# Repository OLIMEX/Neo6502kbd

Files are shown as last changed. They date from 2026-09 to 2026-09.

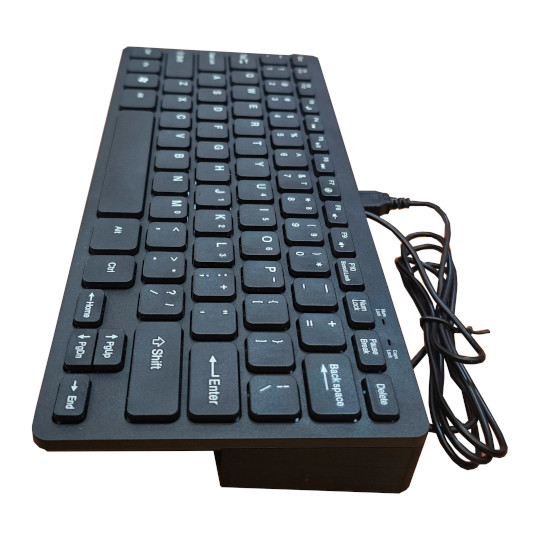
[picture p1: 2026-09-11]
DOCUMENTS/Neo6502kbd-2.jpg

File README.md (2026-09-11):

# Neo6502kbd
Neo6502kbd is all in one Retro computer with 6502 processor, Keyboard, Four USB hosts and DVI/HDMI output.

With Reload emulator you can run Apple ][ and Oric Atmos emulators.

[Neo6502kbd-1](DOCUMENTS/Neo6502kbd-1.jpg)

https://www.olimex.com/Products/Retro-Computers/Neo6502kbd/open-source-hardware

## Licensee
* Hardware is released under CERN Open Hardware Licence Version 2 - Strongly Reciprocal
* Software is released under MIT Licensee
* Documentation is released under CC BY-SA 4.!

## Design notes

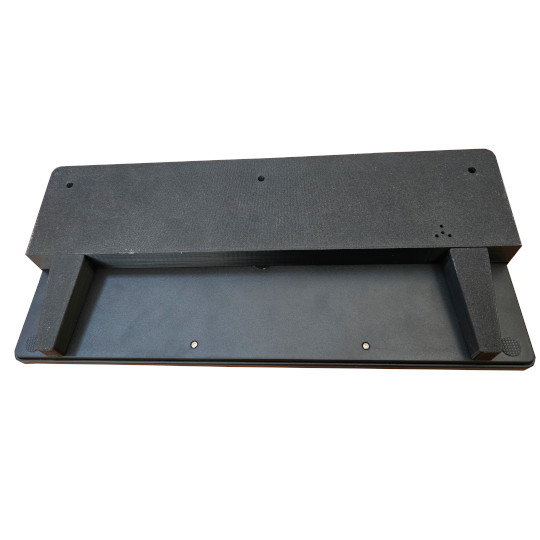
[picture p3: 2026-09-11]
DOCUMENTS/Neo6502kbd-5.jpg

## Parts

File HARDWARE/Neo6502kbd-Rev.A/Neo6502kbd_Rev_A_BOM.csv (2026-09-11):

Quantity | Value | Footprint | Reference
2 | LED/RED/0603 | LED_0603_KA | Act/Sus1, PWR_LED1
1 | SIDE_B3F-3150 | B3F-31XX | BOOT1
1 | PLASTIC CAP BLACK FOR B3F-3150(B32-2010(black)) | BUT-CAP_B32-2010(black) | BOOT1-1
21 | 100nF/10V/20%/X5R/C0402 | C_0402_5MIL_DWS | C1, C2, C3, C4, C5, C6, C7, C8, C9, C10, C13, C14, C22, C24, C32, C37, C38, C39, C41, C42, C44
5 | 2.2uF/6.3V/20%/X5R/C0402 | C_0402_5MIL_DWS | C11, C12, C40, C43, C45
2 | 27pF/50V/5%/C0G/C0402 | C_0402_5MIL_DWS | C15, C16
4 | 22uF/6.3V/20%/X5R/C0603 | C_0603_5MIL_DWS | C18, C28, C35, C36
3 | 10uF/6.3V/20%/X5R/C0402 | C_0402_5MIL_DWS | C20, C21, C23
3 | 47uF/6.3V/20%/X5R/C0805 | C_0805_5MIL_DWS | C27, C33, C34
2 | 1N5822/SS34/SMA | SMA-KA | D1, D3
1 | 1N4148W/SOD123 | SOD-123_1C-2A_KA | D2
1 | HDMI-SWM-19 | HDMI-SWM-19_Paste | DVI1
1 | 1.0uH/4.2A/DCR=35mR/20%/2.00x1.60x1.00mm/L2016(PIM201610-1R0MTS00) | L_2016_MM | L1
4 | LED/GREEN/0603 | LED_0603_KA | LED_HOST1, LED_HOST2, LED_HOST3, LED_HOST4
1 | SS-12D11G5 | SS-12D11G5 | PWR_OFF/ON1
2 | Q12MHz/18pF/30ppm/4P/3.2x2.5mm(ABM8-12.000MHZ-D2Y-T) | TSX-3.2x2.5mm_GND(3) | Q1, Q2
1 | BC817-40(SOT23) | SOT23 | Q3
7 | 2.2k/R0402 | R_0402_5MIL_DWS | R1, R20, R21, R22, R27, R46, R50
15 | 10k/R0402 | R_0402_5MIL_DWS | R2, R13, R14, R16, R17, R19, R24, R28, R29, R30, R31, R32, R41, R42, R43
1 | 1k/R0402 | R_0402_5MIL_DWS | R4
2 | 27R/R0402 | R_0402_5MIL_DWS | R5, R6
4 | 5.1k/1%/R0402 | R_0402_5MIL_DWS | R7, R9, R44, R45
1 | 100R/R0402 | R_0402_5MIL_DWS | R8
1 | 56.2k/1%/R0402 | R_0402_5MIL_DWS | R10
1 | 12.4k/1%/R0402 | R_0402_5MIL_DWS | R11
1 | 33k/R0402 | R_0402_5MIL_DWS | R12
1 | 2.7k/1%/R0402 | R_0402_5MIL_DWS | R15
1 | 4.7k/R0402 | R_0402_5MIL_DWS | R18
1 | 150R/R0402 | R_0402_5MIL_DWS | R23
9 | 270R/R0402 | R_0402_5MIL_DWS | R25, R33, R34, R35, R36, R37, R38, R39, R40
1 | 47R/R1206 | R_1206_5MIL_DWS | R26
3 | 0R/R0402 | R_0402_5MIL_DWS | R47, R48, R49
2 | RA1206_(4x0603)_4B8_330R | RA1206_(4X0603)_4B8_xx | RM1, RM2
1 | Speaker_QMB-09B-03(1.5-5.0V_2.7kHz_F9.0mm*H5.5mm) | Speaker_QMB-09B-03_1-Plus_2-Minus | SPK1
1 | LMUN2235LT1G(SOT-23) | SOT23 | T1
1 | P25Q16SH-SUH-IR(SOIC-8_208mils) | SO-8_208mil | U1
1 | TPS62A02ADRLR(SOT-563-6) | SOT-563-6 | U2
1 | RP2040(QFN-56_7x7mm_P0.4mm) | QFN56_7x7_Pitch_0.4mm | U3
1 | CH217K(SOT23-6L) | SOT23-6 | U4
1 | FE1.1s(SSOP-28) | SSOP28_10x4mm_Pitch_0.64mm | U5
1 | W65C02S6TQTG-14(TQFP44) | TQFP44_NEO6502 | U6
3 | 74LVC245APW(TSSOP20) | TSSOP20_Pitch-0.65mm_6.6x4.5x1.2mm | U7, U8, U9
1 | BH10R | BH10R | UEXT1
4 | USB-A-SMT-6.3H | USB-A-SMT-6.3H_HOST_Female | USB-HOST1, USB-HOST2, USB-HOST3, USB-HOST4
2 | USB-C-16P-F(A40-00119-A52-12) | USB2.0_TYPE-C(A40-00119-A52-12)_Paste | USB-PGM1, USB-PWR1

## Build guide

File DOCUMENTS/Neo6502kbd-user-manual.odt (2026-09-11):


Neo6502kbd

User Manual

Rev.1.0 August 2026 olimex.com

# Introduction to Neo6502

The design goal with Neo6502 was to make simple modern retro computer with 6502 processor.

By modern we mean computer with modern video interface like HDMI, USB keyboard and USB Flash drive as storage. HDMI as everyone have TV with HDMI at home and USB keyboards now are mainstream device for input.

With the task to provide HDMI and USB interface we choose RP2040 which already have DVI bit bang project and USB host.

RP2040 also have enough RAM so we decided to use RP2040 to emulate also the RAM memory for 6502.

For the 6502 processor we choose W65C02 from WDC as they are still in mass production and can be purchased freely.

The Neo name was taken for two reasons, first it imply the modern design, then we liked the analogy with the movie The Matrix as W65C02 lives in virtual world and thinks it have real memory, video and keyboard but actually all this is virtual and emulated by RP2040.

Neo6502 is Open Source Hardware, all CAD files and firmware and available, so people can study and modify.

Neo6502kbd is new derivate of Neo6502 it includes other peripherials which were not available on the original Neo6502 – embedded keyboard and USB hub.

All software and code for Neo6502 will run same way on Neo6502kbd.

The features of Neo6502kbd are:

- real W65C02 processor executing every instruction as it was executed in early retro computers, no emulation for the processor, all timing is exact
- RP2040 with 2MB of SPI Flash, east to load new firmware via drag and drop virtual drive
- HDMI output
- USB host which can be used for programming and to connection to keyboard, mouse, USB Flash etc
- Audio buzzer which you can enable/disable
- USB-C connector for power supply and programming
- UEXT connector with I2C, UART and SPI for connecting to external boards
- On Off slide switch
- RP2040 programming bootloader button
- Dimension 285 x 123 x30mm

## Order codes for Neo6502kbd and accessories:

Neo6502kbd (https://www.olimex.com/Products/Retro-Computers/Neo6502kbd/open-source-hardware) All in one modern retro computer with 6502 processor

CABLE-USB-A-C-1M (https://www.olimex.com/Products/Components/Cables/CABLE-USB-A-C-1M/) USB-C cable for power supply

CABLE-HDMI-50CM (https://www.olimex.com/Products/Components/Cables/CABLE-HDMI-50CM/) HDMI cable

UEXT modules (https://www.olimex.com/Products/Modules/) many UEXT modules which can connect to Neo6502 UEXT connector

# HARDWARE

## Neo6502kbd layout:

Back view:


Power USB-C

DVI/HDMI

Four USB-C hosts

## Neo6502kbd schematics:

Neo6502kbd latest schematic is on GitHub (https://github.com/OLIMEX/Neo6502kbd/blob/main/HARDWARE/Neo6502kbd-Rev.A/Neo6502kbd_Rev_A.pdf)

## UEXT connector:

UEXT connector stands for Universal EXTension connector and contain +3.3V, GND, I2C, SPI, UART signals.

UEXT connector can be in different shapes.

The original UEXT connector is 0.1” 2.54mm step boxed plastic connector. All signals are with 3.3V levels.

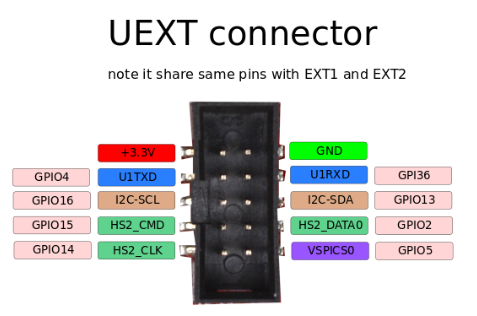
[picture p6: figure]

Olimex has developed number of MODULES (https://www.olimex.com/Products/Modules/) with this connector. There are temperature, humidity, pressure, magnetic field, light sensors. Modules with LCDs, LED matrix, Relays, Bluetooth, Zigbee, WiFi, GSM, GPS, RFID, RTC, EKG, sensors and etc.

Neo6502kbd UEXT connector is wired to RP2040 GPIOs as follows:

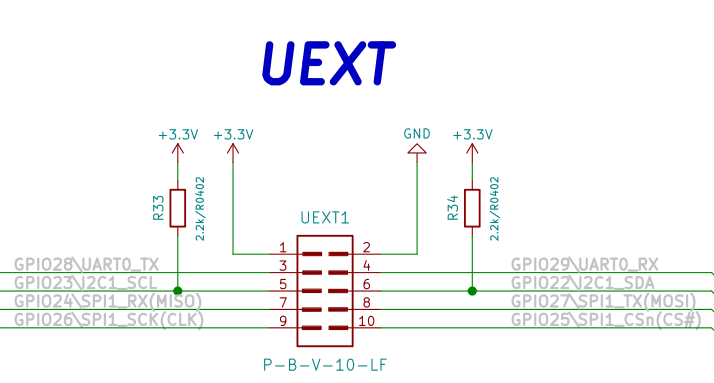
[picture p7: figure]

# SOFTWARE:

Neo6502 is open flexible system as everything is virtual and depend on RP2040 firmware, this allow you to emulate old architectures like Apple ][ and Oric Atmos, or to make your own completely new architecture.

Veselin Sladkov (veselin.sladkov@gmail.com) did amazing work for Neo6502 and created Apple ][, Oric Atmos and Apple Iic emulation with Reload emulator (https://github.com/vsladkov/reload-emulator).

The reload emulator require some ROMs and disks which are hosted on olimex’s ftp (https://ftp.olimex.com/Neo6502/).

Rien Matthijsse (rien@marobi.com) made several versions of RP2040 memulator and EHBasic port working on Neo6502 in his GitHub repository (https://github.com/marobi).

Paul Robson (paul@robsons.org.uk ) made special version of Neo6502 Basic on GitHub (https://github.com/paulscottrobson/neo6502) and web browser emulator (http://www.robsons.org.uk/neo6502/neo.html).

## Programming RP2040

The RP2040 firmware is UF2 file. You can get pre-build firmware of reload emulator on olimex’s ftp.

We recommend you for Apple ][ to use: https://ftp.olimex.com/Neo6502/uf2/apple2_800x600_400MHz.uf2

This firmware have latest PRODOS and several games on it ready to play.

For Oric Atmos we recommend you to use:

https://ftp.olimex.com/Neo6502/uf2/oric_960x540_372MHz.uf2

To play Total Replay you need this uf2 file:

https://ftp.olimex.com/Neo6502/apple2e-5.uf2

And you need USB Flash drive with Total Replay 5.1

https://ftp.olimex.com/Neo6502/Total%20Replay%20v5.1.hdv

To program the .uf2 files you need USB A to C cable.

Plug the cable to the left side USB-C connector (PGM)

Press the bootloader button and switch the power on. Your computer will show new drive. Once this new drive show copy the .uf2 file to it. Once the firmware is programmed the drive will dissapear. This means the RP2040 now have the new firmware loaded.

You need to disconnect the cable and to attach it to the back side USB-C power supply connector.

# Revision History

Revision 1.0 August 2026

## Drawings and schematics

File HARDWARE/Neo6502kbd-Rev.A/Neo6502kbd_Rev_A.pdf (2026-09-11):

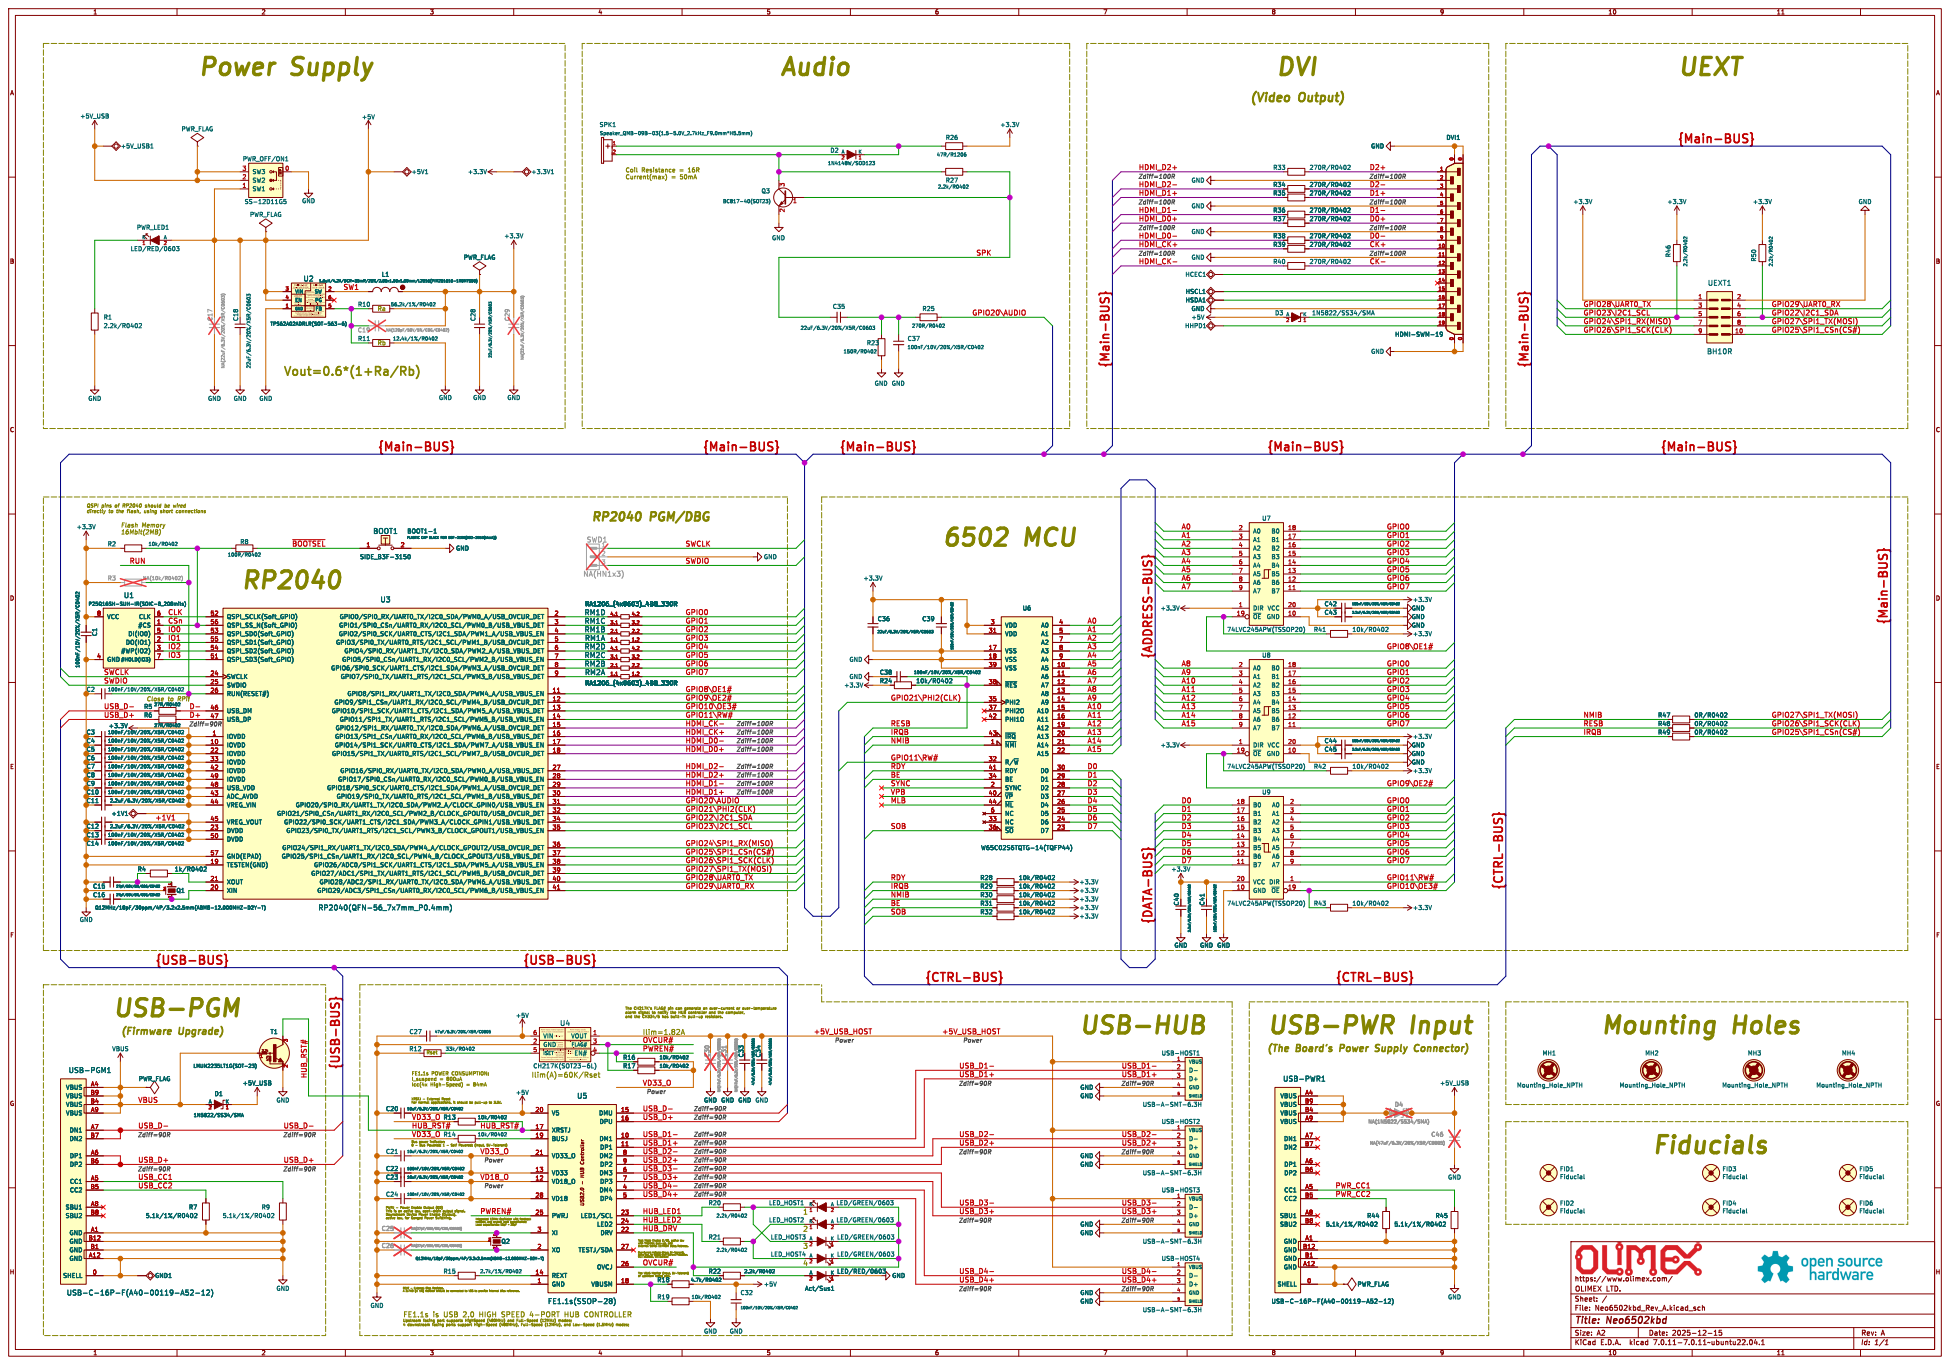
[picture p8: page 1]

In casea loweroutputrippleisdesired,higheroutputcapacitancecanhelpreducetheripple. Lx=1.0uH
Cout=(10~22)uF/6.3V/X5Rþÿ(Vout"e1.8V). 22uFRecommended! Cout=22uF/6.3V/X5Rþÿ(1.2V"dVout<1.8V) Cout=44uF/6.3V/X5Rþÿ(0.6V"dVout<1.2V) DCR<50mR

Donotfloat. Enablecontrol. FB Input Current,I(FB)=100nA(max) FeedbackReferenceVoltage,V(REF)=0.6V
Rb mustnotbehigherthanþÿ100k© toprovideacceptablenoisesensitivity. ShutdownCurrentI(SHDN)=0.01-2uA
SwitchingFrequency 2.4MHz TPS62A02ADRLR V(ENH)=1.2V

Rb Vout=0.6*(1+Ra/Rb)

QSPI pins of RP2040 should be wired
directly to the flash, using short connections Flash Memory

PLASTIC CAP BLACK FOR B3F-3150(B32-2010(black))

connectedto USBportVBUS Currentlimiting thresholdsetting, externalresistorRsetto GND to setIset ground

alarmopen-drainoutput,activelow Common
terminal VIH=(1.8-5.0)V

(The Board's Power Supply Connector)

5 USB-HOST3 USB-A-SMT-6.3H GND

File: Neo6502kbd_Rev_A.kicad_sch Sheet: / OLIMEX LTD. https://www.olimex.com/

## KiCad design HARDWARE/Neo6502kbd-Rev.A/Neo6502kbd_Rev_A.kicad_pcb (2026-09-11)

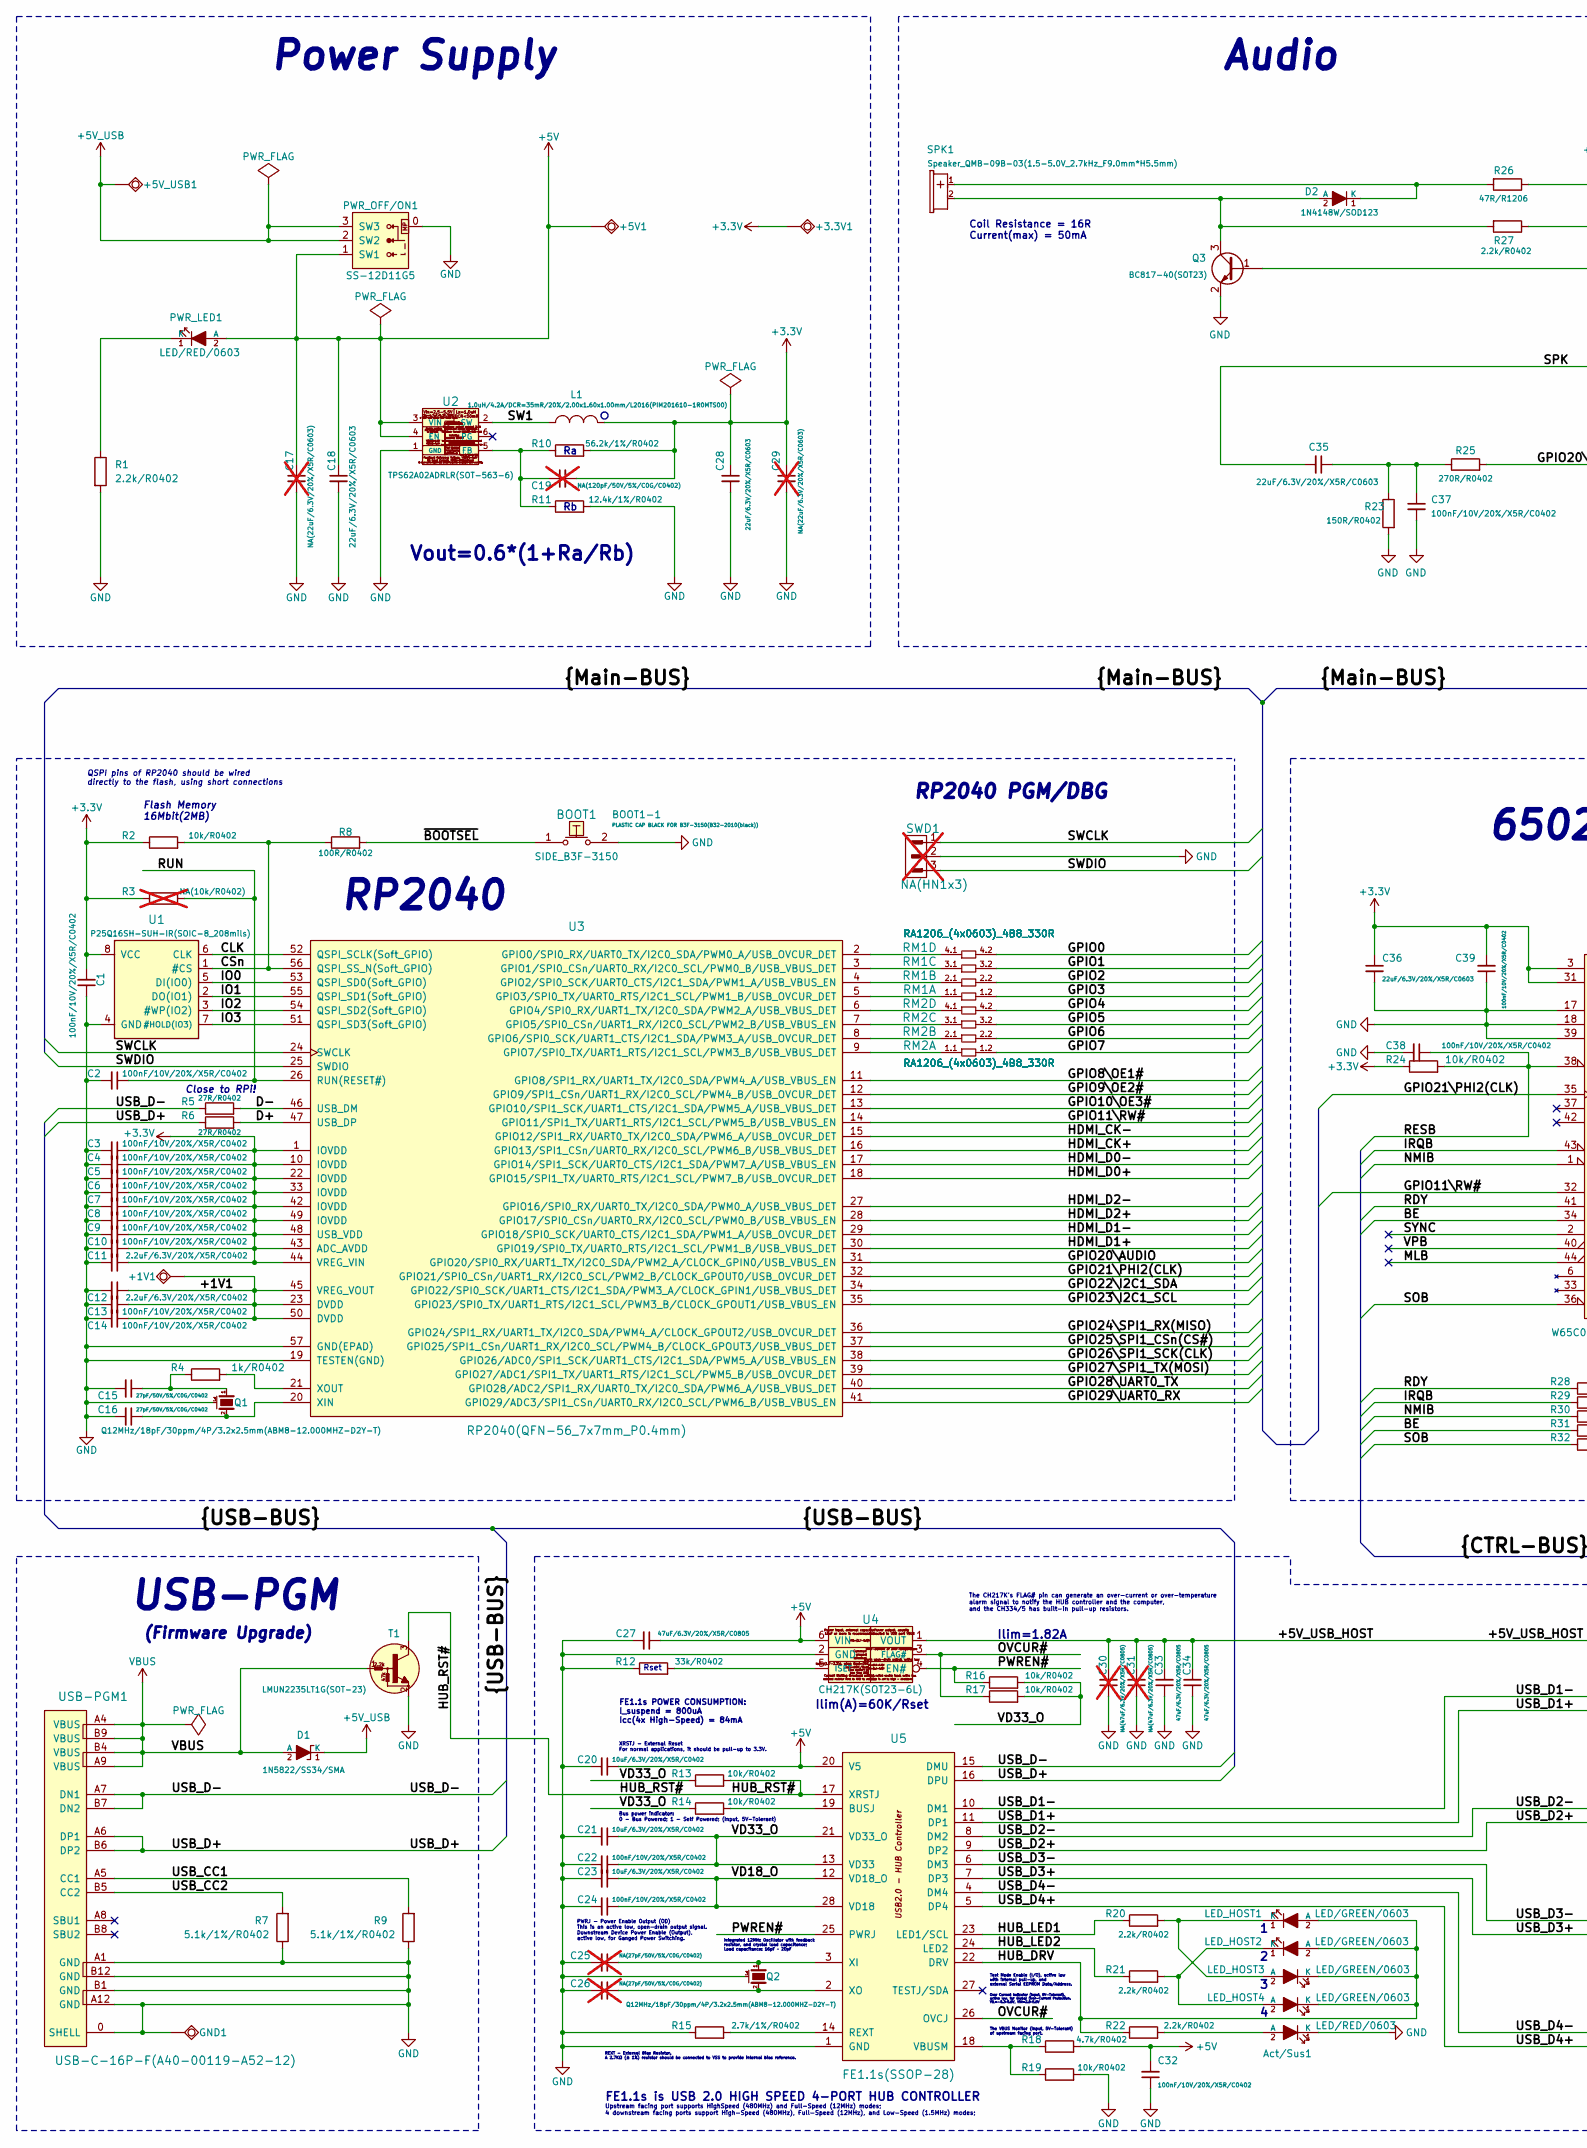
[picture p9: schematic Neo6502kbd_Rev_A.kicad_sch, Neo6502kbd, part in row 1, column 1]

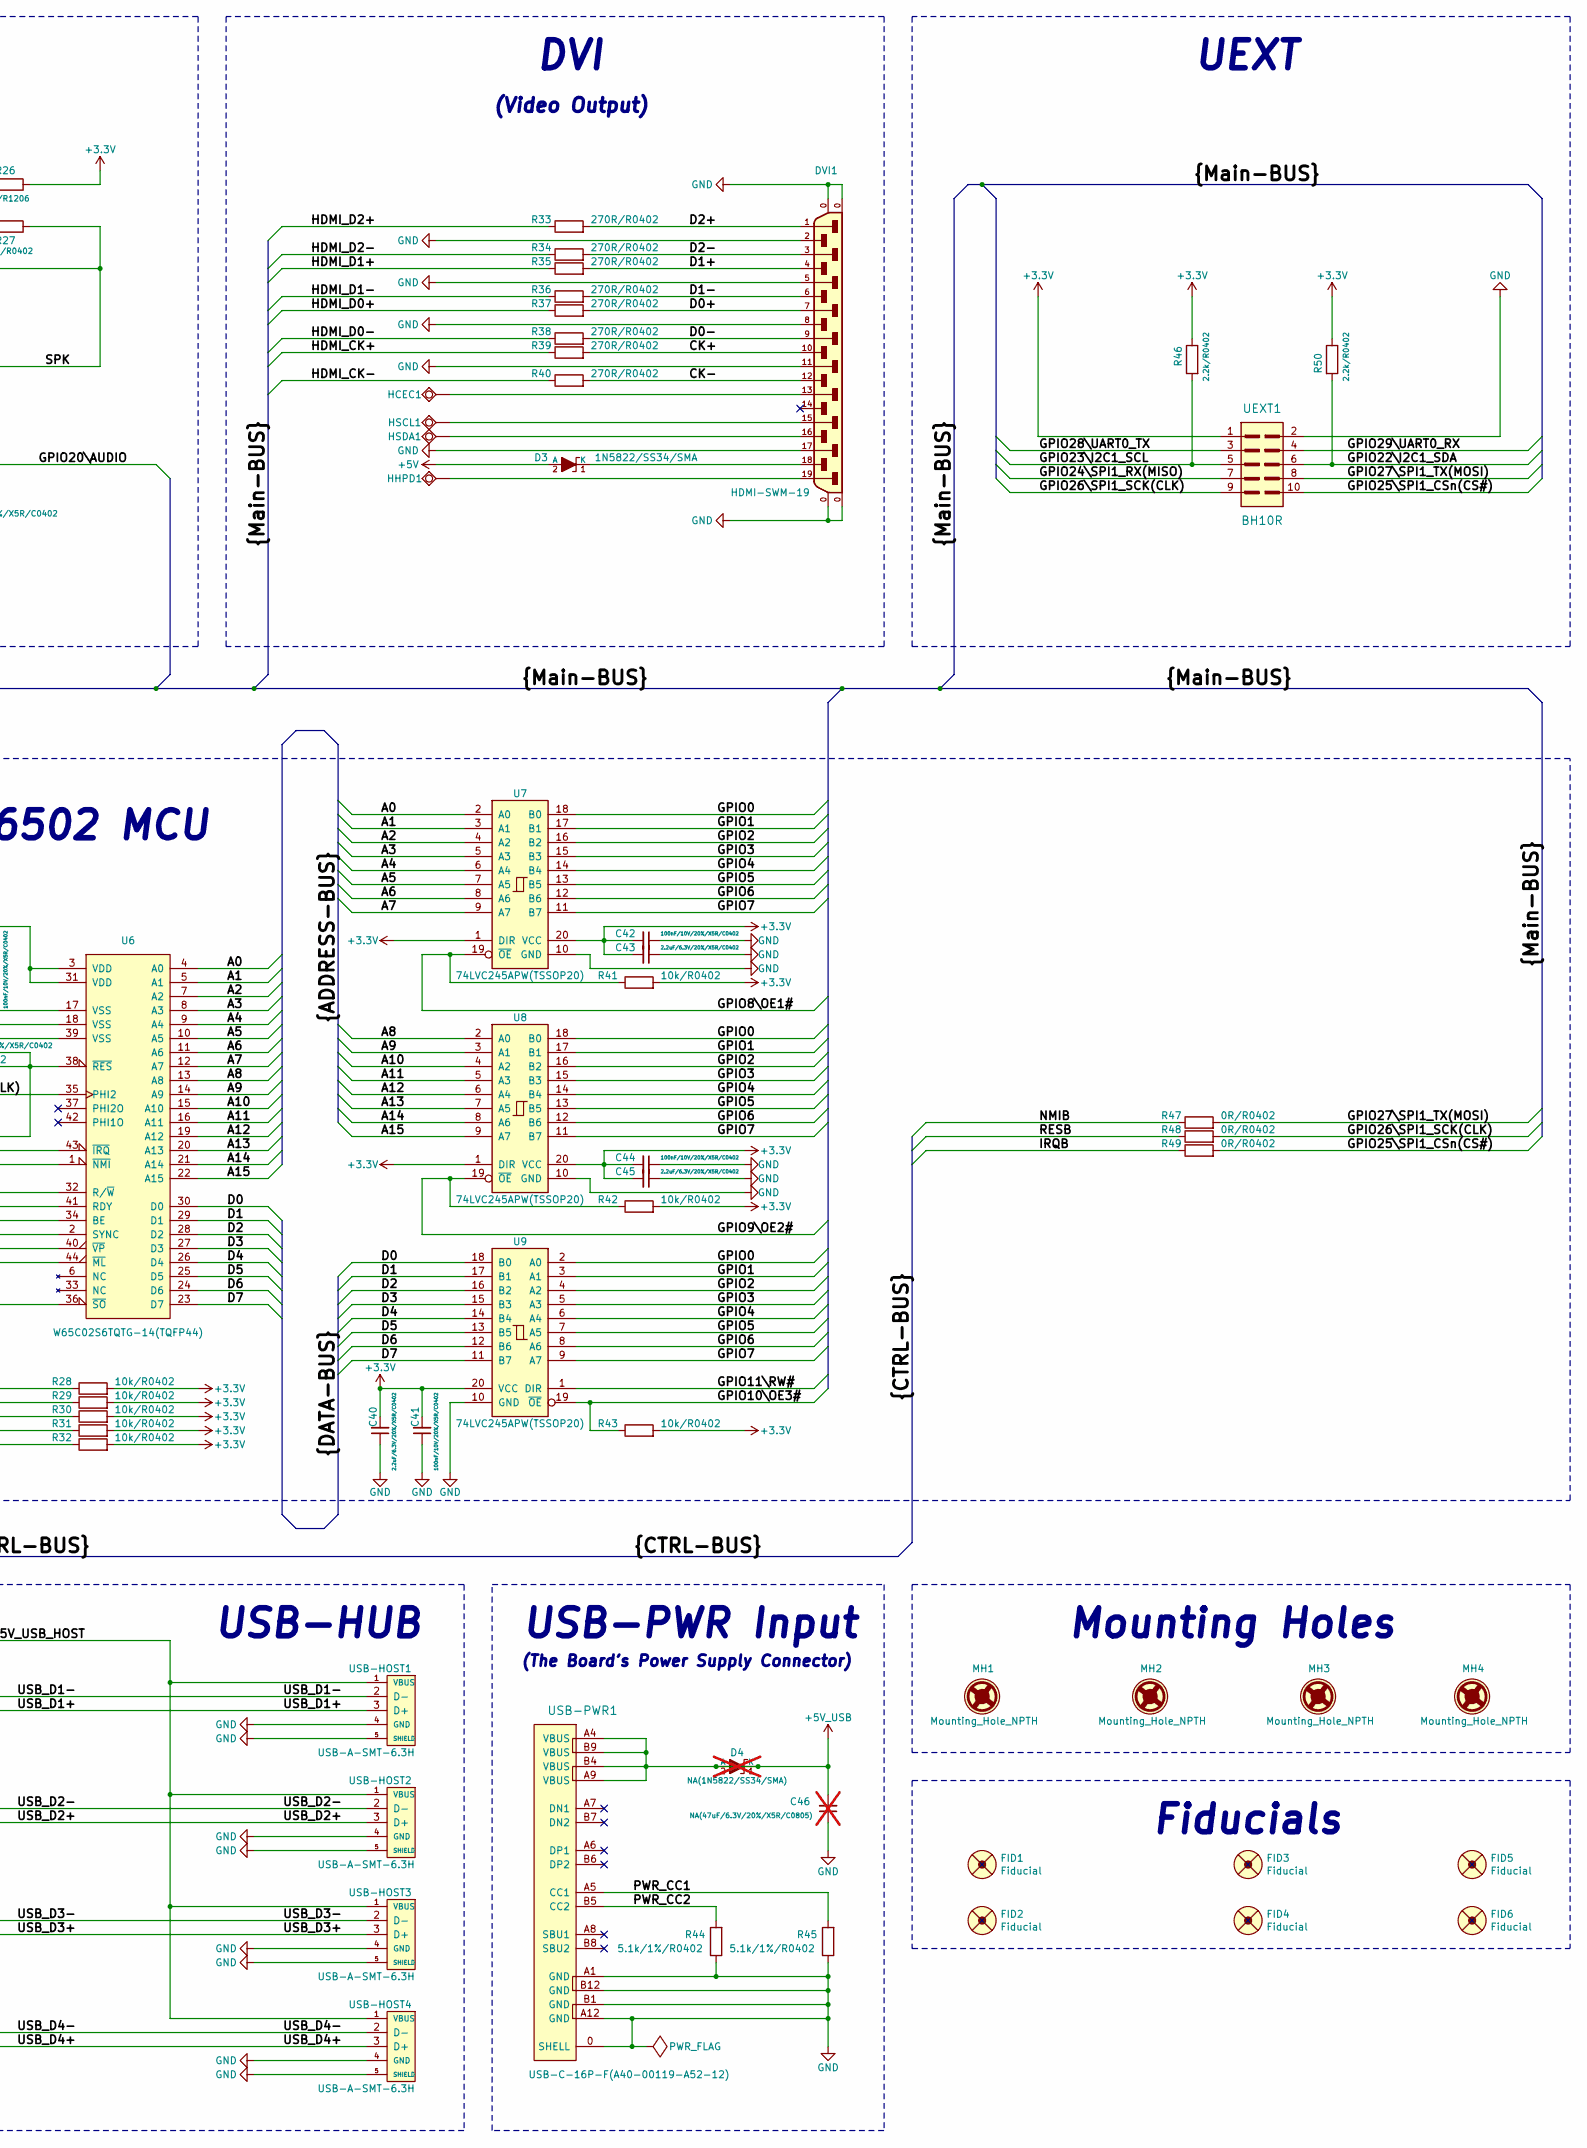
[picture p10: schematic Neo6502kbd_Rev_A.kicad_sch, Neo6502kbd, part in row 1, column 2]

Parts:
+1V1, +3.3V1, +5V1, +5V_USB1: TESTPAD; TEST_PAD40x70_SQUARE
Act/Sus1: LED/RED/0603; LED_0603_KA
BOOT1: SIDE_B3F-3150; B3F-31XX
BOOT1-1: PLASTIC CAP BLACK FOR B3F-3150(B32-2010(black)); BUT-CAP_B32-2010(black)
C1, C2, C3, C4, C5, C6, C7, C8, C9, C10, C13, C14, C22, C24, C32, C37, C38, C39, C41, C42, C44: 100nF/10V/20%/X5R/C0402; C_0402_5MIL_DWS
C11, C12, C40, C43, C45: 2.2uF/6.3V/20%/X5R/C0402; C_0402_5MIL_DWS
C15, C16: 27pF/50V/5%/C0G/C0402; C_0402_5MIL_DWS
C17, C29: NA(22uF/6.3V/20%/X5R/C0603); C_0603_5MIL_DWS; not fitted
C18, C28, C35, C36: 22uF/6.3V/20%/X5R/C0603; C_0603_5MIL_DWS
C19: NA(120pF/50V/5%/C0G/C0402); C_0402_5MIL_DWS; not fitted
C20, C21, C23: 10uF/6.3V/20%/X5R/C0402; C_0402_5MIL_DWS
C25, C26: NA(27pF/50V/5%/C0G/C0402); C_0402_5MIL_DWS; not fitted
C27, C33, C34: 47uF/6.3V/20%/X5R/C0805; C_0805_5MIL_DWS
C30, C31, C46: NA(47uF/6.3V/20%/X5R/C0805); C_0805_5MIL_DWS; not fitted
D1, D3: 1N5822/SS34/SMA; SMA-KA
D2: 1N4148W/SOD123; SOD-123_1C-2A_KA
D4: NA(1N5822/SS34/SMA); SMA-KA; not fitted
DVI1: HDMI-SWM-19; HDMI-SWM-19_Paste
FID1, FID2, FID3: Fiducial; Fiducial1x3_Paste
FID4, FID5, FID6: Fiducial; Fiducial1x3
GND1: TESTPAD; TEST_PAD40x70_SQUARE
HCEC1: TESTPAD; TESTPAD_40-ROUND
HHPD1: TESTPAD; TESTPAD_40-ROUND
HSCL1: TESTPAD; TESTPAD_40-ROUND
HSDA1: TESTPAD; TESTPAD_40-ROUND
L1: 1.0uH/4.2A/DCR=35mR/20%/2.00x1.60x1.00mm/L2016(PI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; L_2016_MM
LED_HOST1, LED_HOST2, LED_HOST3, LED_HOST4: LED/GREEN/0603; LED_0603_KA
MH1, MH2, MH3, MH4: Mounting_Hole_NPTH; Mounting_Hole_Drill-3.3mm_Clerance-7mm
PWR_LED1: LED/RED/0603; LED_0603_KA
PWR_OFF/ON1: SS-12D11G5
Q1, Q2: Q12MHz/18pF/30ppm/4P/3.2x2.5mm(ABM8-12.000MHZ-D2Y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; TSX-3.2x2.5mm_GND(3)
Q3: BC817-40(SOT23); SOT23
R1, R20, R21, R22, R27, R46, R50: 2.2k/R0402; R_0402_5MIL_DWS
R2, R13, R14, R16, R17, R19, R24, R28, R29, R30, R31, R32, R41, R42, R43: 10k/R0402; R_0402_5MIL_DWS
R3: NA(10k/R0402); R_0402_5MIL_DWS; not fitted
R4: 1k/R0402; R_0402_5MIL_DWS
R5, R6: 27R/R0402; R_0402_5MIL_DWS
R7, R9, R44, R45: 5.1k/1%/R0402; R_0402_5MIL_DWS
R8: 100R/R0402; R_0402_5MIL_DWS
R10: 56.2k/1%/R0402; R_0402_5MIL_DWS
R11: 12.4k/1%/R0402; R_0402_5MIL_DWS
R12: 33k/R0402; R_0402_5MIL_DWS
R15: 2.7k/1%/R0402; R_0402_5MIL_DWS
R18: 4.7k/R0402; R_0402_5MIL_DWS
R23: 150R/R0402; R_0402_5MIL_DWS
R25, R33, R34, R35, R36, R37, R38, R39, R40: 270R/R0402; R_0402_5MIL_DWS
R26: 47R/R1206; R_1206_5MIL_DWS
R47, R48, R49: 0R/R0402; R_0402_5MIL_DWS
RM1, RM2: RA1206_(4x0603)_4B8_330R; RA1206_(4X0603)_4B8_xx
SPK1: Speaker_QMB-09B-03(1.5-5.0V_2.7kHz_F9.0mm*H5.5mm); Speaker_QMB-09B-03_1-Plus_2-Minus
SWD1: NA(HN1x3); HN1x3; not fitted
T1: LMUN2235LT1G(SOT-23); SOT23
U1: P25Q16SH-SUH-IR(SOIC-8_208mils); SO-8_208mil
U2: TPS62A02ADRLR(SOT-563-6); SOT-563-6
U3: RP2040(QFN-56_7x7mm_P0.4mm); QFN56_7x7_Pitch_0.4mm
U4: CH217K(SOT23-6L); SOT23-6
U5: FE1.1s(SSOP-28); SSOP28_10x4mm_Pitch_0.64mm
U6: W65C02S6TQTG-14(TQFP44); TQFP44_NEO6502
U7, U8, U9: 74LVC245APW(TSSOP20); TSSOP20_Pitch-0.65mm_6.6x4.5x1.2mm
UEXT1: BH10R
USB-HOST1, USB-HOST2, USB-HOST3, USB-HOST4: USB-A-SMT-6.3H; USB-A-SMT-6.3H_HOST_Female
USB-PGM1: USB-C-16P-F(A40-00119-A52-12); USB2.0_TYPE-C(A40-00119-A52-12)_Paste
USB-PWR1: USB-C-16P-F(A40-00119-A52-12); USB2.0_TYPE-C(A40-00119-A52-12)_Paste

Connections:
+3.3V: +3.3V1.1 (Pad), C1.2, C3.1, C4.1, C5.1, C6.1, C7.1, C8.1, C9.1, C10.1, C11.1, C19.2, C28.1, C29.1, C36.1, C39.2, C40.2, C41.2, C42.2, C43.2, C44.2, C45.2, L1.2, R2.1, R3.1, R10.2, R24.1, R26.1, R28.2, R29.2, R30.2, R31.2, R32.2, R41.2, R42.2, R43.2, R46.1, R50.1, U1.8 (VCC), U3.1 (IOVDD), U3.10 (IOVDD), U3.22 (IOVDD), U3.33 (IOVDD), U3.42 (IOVDD), U3.43 (ADC_AVDD), U3.44 (VREG_VIN), U3.48 (USB_VDD), U3.49 (IOVDD), U6.3 (VDD), U6.31 (VDD), U7.1 (DIR), U7.20 (VCC), U8.1 (DIR), U8.20 (VCC), U9.20 (VCC), UEXT1.1
+5V: +5V1.1 (Pad), C17.1, C18.1, C20.1, C27.1, C32.2, D3.2 (A), PWR_LED1.2 (A), PWR_OFF/ON1.1 (SW1), R18.2, U2.3 (VIN), U2.4 (EN), U4.6 (VIN), U5.20 (V5)
+5V_USB: +5V_USB1.1 (Pad), C46.2, D1.1 (K), D4.1 (K), D4.2 (A), PWR_OFF/ON1.2 (SW2), PWR_OFF/ON1.3 (SW3), USB-PWR1.A4 (VBUS), USB-PWR1.A9 (VBUS), USB-PWR1.B4 (VBUS), USB-PWR1.B9 (VBUS)
/+1V1: +1V1.1 (Pad), C12.1, C13.1, C14.1, U3.23 (DVDD), U3.45 (VREG_VOUT), U3.50 (DVDD)
/+5V_USB_HOST: C30.2, C31.2, C33.2, C34.2, U4.1 (VOUT), USB-HOST1.1 (VBUS), USB-HOST2.1 (VBUS), USB-HOST3.1 (VBUS), USB-HOST4.1 (VBUS)
/A0: U6.4 (A0), U7.2 (A0)
/A1: U6.5 (A1), U7.3 (A1)
/A2: U6.7 (A2), U7.4 (A2)
/A3: U6.8 (A3), U7.5 (A3)
/A4: U6.9 (A4), U7.6 (A4)
/A5: U6.10 (A5), U7.7 (A5)
/A6: U6.11 (A6), U7.8 (A6)
/A7: U6.12 (A7), U7.9 (A7)
/A8: U6.13 (A8), U8.2 (A0)
/A9: U6.14 (A9), U8.3 (A1)
/A10: U6.15 (A10), U8.4 (A2)
/A11: U6.16 (A11), U8.5 (A3)
/A12: U6.19 (A12), U8.6 (A4)
/A13: U6.20 (A13), U8.7 (A5)
/A14: U6.21 (A14), U8.8 (A6)
/A15: U6.22 (A15), U8.9 (A7)
/BE: R31.1, U6.34 (BE)
/CK+: DVI1.10, R39.2
/CK-: DVI1.12, R40.2
/CLK: U1.6 (CLK), U3.52 (QSPI_SCLK(Soft_GPIO))
/CSn: R2.2, R8.1, U1.1 (#CS), U3.56 (QSPI_SS_N(Soft_GPIO))
/D0: U6.30 (D0), U9.18 (B0)
/D0+: DVI1.7, R37.2
/D0-: DVI1.9, R38.2
/D1: U6.29 (D1), U9.17 (B1)
/D1+: DVI1.4, R35.2
/D1-: DVI1.6, R36.2
/D2: U6.28 (D2), U9.16 (B2)
/D2+: DVI1.1, R33.2
/D2-: DVI1.3, R34.2
/D3: U6.27 (D3), U9.15 (B3)
/D4: U6.26 (D4), U9.14 (B4)
/D5: U6.25 (D5), U9.13 (B5)
/D6: U6.24 (D6), U9.12 (B6)
/D7: U6.23 (D7), U9.11 (B7)
/D+: R6.2, U3.47 (USB_DP)
/D-: R5.2, U3.46 (USB_DM)
/GPIO0: RM1.4.2, U7.18 (B0), U8.18 (B0), U9.2 (A0)
/GPIO1: RM1.3.2, U7.17 (B1), U8.17 (B1), U9.3 (A1)
/GPIO2: RM1.2.2, U7.16 (B2), U8.16 (B2), U9.4 (A2)
/GPIO3: RM1.1.2, U7.15 (B3), U8.15 (B3), U9.5 (A3)
/GPIO4: RM2.4.2, U7.14 (B4), U8.14 (B4), U9.6 (A4)
/GPIO5: RM2.3.2, U7.13 (B5), U8.13 (B5), U9.7 (A5)
/GPIO6: RM2.2.2, U7.12 (B6), U8.12 (B6), U9.8 (A6)
/GPIO7: RM2.1.2, U7.11 (B7), U8.11 (B7), U9.9 (A7)
/GPIO8\OE1#: R41.1, U3.11 (GPIO8/SPI1_RX/UART1_TX/I2C0_SDA/PWM4_A/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), U7.19 (~OE)
/GPIO9\OE2#: R42.1, U3.12 (GPIO9/SPI1_CSn/UART1_RX/I2C0_SCL/PWM4_B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), U8.19 (~OE)
/GPIO10\OE3#: R43.1, U3.13 (GPIO10/SPI1_SCK/UART1_CTS/I2C1_SDA/PWM5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), U9.19 (~OE)
/GPIO11\RW#: U3.14 (GPIO11/SPI1_TX/UART1_RTS/I2C1_SCL/PWM5_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), U6.32 (R/~W), U9.1 (DIR)
/GPIO20\AUDIO: R25.2, U3.31 (GPIO20/SPI0_RX/UART1_TX/I2C0_SDA/PWM2_A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)
/GPIO21\PHI2(CLK): U3.32 (GPIO21/SPI0_CSn/UART1_RX/I2C0_SCL/PWM2_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), U6.35 (PHI2)
/GPIO22\I2C1_SDA: R50.2, U3.34 (GPIO22/SPI0_SCK/UART1_CTS/I2C1_SDA/PWM3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), UEXT1.6
/GPIO23\I2C1_SCL: R46.2, U3.35 (GPIO23/SPI0_TX/UART1_RTS/I2C1_SCL/PWM3_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), UEXT1.5
/GPIO24\SPI1_RX(MISO): U3.36 (GPIO24/SPI1_RX/UART1_TX/I2C0_SDA/PWM4_A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), UEXT1.7
/GPIO25\SPI1_CSn(CS#): R49.2, U3.37 (GPIO25/SPI1_CSn/UART1_RX/I2C0_SCL/PWM4_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), UEXT1.10
/GPIO26\SPI1_SCK(CLK): R48.2, U3.38 (GPIO26/ADC0/SPI1_SCK/UART1_CTS/I2C1_SDA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), UEXT1.9
/GPIO27\SPI1_TX(MOSI): R47.2, U3.39 (GPIO27/ADC1/SPI1_TX/UART1_RTS/I2C1_SCL/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), UEXT1.8
/GPIO28\UART0_TX: U3.40 (GPIO28/ADC2/SPI1_RX/UART0_TX/I2C0_SDA/P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), UEXT1.3
/GPIO29\UART0_RX: U3.41 (GPIO29/ADC3/SPI1_CSn/UART0_RX/I2C0_SCL/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), UEXT1.4
/HDMI_CK+: R39.1, U3.16 (GPIO13/SPI1_CSn/UART0_RX/I2C0_SCL/PWM6_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)
/HDMI_CK-: R40.1, U3.15 (GPIO12/SPI1_RX/UART0_TX/I2C0_SDA/PWM6_A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)
/HDMI_D0+: R37.1, U3.18 (GPIO15/SPI1_TX/UART0_RTS/I2C1_SCL/PWM7_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)
/HDMI_D0-: R38.1, U3.17 (GPIO14/SPI1_SCK/UART0_CTS/I2C1_SDA/PWM7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)
/HDMI_D1+: R35.1, U3.30 (GPIO19/SPI0_TX/UART0_RTS/I2C1_SCL/PWM1_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)
/HDMI_D1-: R36.1, U3.29 (GPIO18/SPI0_SCK/UART0_CTS/I2C1_SDA/PWM1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)
/HDMI_D2+: R33.1, U3.28 (GPIO17/SPI0_CSn/UART0_RX/I2C0_SCL/PWM0_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)
/HDMI_D2-: R34.1, U3.27 (GPIO16/SPI0_RX/UART0_TX/I2C0_SDA/PWM0_A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)
/HUB_DRV: LED_HOST1.2 (A), LED_HOST2.2 (A), LED_HOST3.1 (K), LED_HOST4.1 (K), R22.1, U5.22 (DRV)
/HUB_LED1: R20.1, U5.23 (LED1/SCL)
/HUB_LED2: R21.1, U5.24 (LED2)
/HUB_RST#: R13.2, T1.3 (C), U5.17 (XRSTJ)
/IO0: U1.5 (DI(IO0)), U3.53 (QSPI_SD0(Soft_GPIO))
/IO1: U1.2 (DO(IO1)), U3.55 (QSPI_SD1(Soft_GPIO))
/IO2: U1.3 (#WP(IO2)), U3.54 (QSPI_SD2(Soft_GPIO))
/IO3: U1.7 (#HOLD(IO3)), U3.51 (QSPI_SD3(Soft_GPIO))
/IRQB: R29.1, R49.1, U6.43 (~IRQ)
/MLB: U6.44 (~ML)
/NMIB: R30.1, R47.1, U6.1 (~NMI)
/OVCUR#: R17.1, U4.3 (FLAG#), U5.26 (OVCJ)
/PWREN#: R16.1, U4.4 (EN#), U5.25 (PWRJ)
/PWR_CC1: R45.2, USB-PWR1.A5 (CC1)
/PWR_CC2: R44.2, USB-PWR1.B5 (CC2)
/RDY: R28.1, U6.41 (RDY)
/RESB: C38.1, R24.2, R48.1, U6.38 (~RES)
/RUN: C2.1, R3.2, U3.26 (RUN(RESET#))
/SOB: R32.1, U6.36 (~SO)
/SPK: C35.2, Q3.1 (B), R27.1
/SW1: L1.1, U2.2 (SW)
/SWCLK: SWD1.1, U3.24 (SWCLK)
/SWDIO: SWD1.3, U3.25 (SWDIO)
/SYNC: U6.2 (SYNC)
/USB_CC1: R9.2, USB-PGM1.A5 (CC1)
/USB_CC2: R7.2, USB-PGM1.B5 (CC2)
/USB_D1+: U5.11 (DP1), USB-HOST1.3 (D+)
/USB_D1-: U5.10 (DM1), USB-HOST1.2 (D-)
/USB_D2+: U5.9 (DP2), USB-HOST2.3 (D+)
/USB_D2-: U5.8 (DM2), USB-HOST2.2 (D-)
/USB_D3+: U5.7 (DP3), USB-HOST3.3 (D+)
/USB_D3-: U5.6 (DM3), USB-HOST3.2 (D-)
/USB_D4+: U5.5 (DP4), USB-HOST4.3 (D+)
/USB_D4-: U5.4 (DM4), USB-HOST4.2 (D-)
/USB_D+: R6.1, U5.16 (DPU), USB-PGM1.A6 (DP1), USB-PGM1.B6 (DP2)
/USB_D-: R5.1, U5.15 (DMU), USB-PGM1.A7 (DN1), USB-PGM1.B7 (DN2)
/VD18_O: C23.1, C24.1, U5.12 (VD18_O), U5.28 (VD18)
/VD33_O: C21.1, C22.1, R13.1, R14.1, R16.2, R17.2, U5.13 (VD33), U5.21 (VD33_O)
/VPB: U6.40 (~VP)
/~BOOTSEL: BOOT1.1, R8.2
GND: Act/Sus1.1 (K), BOOT1.2, C1.1, C2.2, C3.2, C4.2, C5.2, C6.2, C7.2, C8.2, C9.2, C10.2, C11.2, C12.2, C13.2, C14.2, C15.2, C16.2, C17.2, C18.2, C20.2, C21.2, C22.2, C23.2, C24.2, C25.2, C26.2, C27.2, C28.2, C29.2, C30.1, C31.1, C32.1, C33.1, C34.1, C36.2, C37.2, C38.2, C39.1, C40.1, C41.1, C42.1, C43.1, C44.1, C45.1, C46.1, DVI1.0 (23), DVI1.2, DVI1.5, DVI1.8, DVI1.11, DVI1.17, GND1.1 (Pad), PWR_OFF/ON1.0, Q1.3 (case), Q2.3 (case), Q3.2 (E), R1.2, R7.1, R9.1, R11.2, R12.1, R15.1, R19.2, R23.2, R44.1, R45.1, SWD1.2, T1.2 (E), U1.4 (GND), U2.1 (GND), U3.19 (TESTEN(GND)), U3.57 (GND(EPAD)), U4.2 (GND), U5.1 (GND), U6.17 (VSS), U6.18 (VSS), U6.39 (VSS), U7.10 (GND), U8.10 (GND), U9.10 (GND), UEXT1.2, USB-HOST1.4 (GND), USB-HOST1.5 (SHIELD), USB-HOST2.4 (GND), USB-HOST2.5 (SHIELD), USB-HOST3.4 (GND), USB-HOST3.5 (SHIELD), USB-HOST4.4 (GND), USB-HOST4.5 (SHIELD), USB-PGM1.0 (SHELL), USB-PGM1.A1 (GND), USB-PGM1.A12 (GND), USB-PGM1.B1 (GND), USB-PGM1.B12 (GND), USB-PWR1.0 (SHELL), USB-PWR1.A1 (GND), USB-PWR1.A12 (GND), USB-PWR1.B1 (GND), USB-PWR1.B12 (GND)
unnamed: Act/Sus1.2 (A), R22.2
unnamed: C15.1, Q1.1, R4.1
unnamed: C35.1, C37.1, R23.1, R25.1
unnamed: D2.2 (A), Q3.3 (C), R27.2, SPK1.2 (MINUS)
unnamed: D2.1 (K), R26.2, SPK1.1 (PLUS)
unnamed: D3.1 (K), DVI1.18
unnamed: DVI1.13, HCEC1.1 (Pad)
unnamed: DVI1.15, HSCL1.1 (Pad)
unnamed: DVI1.16, HSDA1.1 (Pad)
unnamed: DVI1.19, HHPD1.1 (Pad)
unnamed: LED_HOST1.1 (K), LED_HOST3.2 (A), R20.2
unnamed: LED_HOST2.1 (K), LED_HOST4.2 (A), R21.2
unnamed: PWR_LED1.1 (K), R1.1
unnamed: C19.1, R10.1, R11.1, U2.5 (FB)
unnamed: RM1.4.1, U3.2 (GPIO0/SPI0_RX/UART0_TX/I2C0_SDA/PWM0_A/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)
unnamed: RM1.3.1, U3.3 (GPIO1/SPI0_CSn/UART0_RX/I2C0_SCL/PWM0_B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)
unnamed: RM1.2.1, U3.4 (GPIO2/SPI0_SCK/UART0_CTS/I2C1_SDA/PWM1_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)
unnamed: RM1.1.1, U3.5 (GPIO3/SPI0_TX/UART0_RTS/I2C1_SCL/PWM1_B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)
unnamed: RM2.4.1, U3.6 (GPIO4/SPI0_RX/UART1_TX/I2C0_SDA/PWM2_A/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)
unnamed: RM2.3.1, U3.7 (GPIO5/SPI0_CSn/UART1_RX/I2C0_SCL/PWM2_B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)
unnamed: RM2.2.1, U3.8 (GPIO6/SPI0_SCK/UART1_CTS/I2C1_SDA/PWM3_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)
unnamed: RM2.1.1, U3.9 (GPIO7/SPI0_TX/UART1_RTS/I2C1_SCL/PWM3_B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)
unnamed: C16.1, Q1.2, U3.20 (XIN)
unnamed: R4.2, U3.21 (XOUT)
unnamed: R12.2, U4.5 (ISET)
unnamed: R14.2, U5.19 (BUSJ)
unnamed: R15.2, U5.14 (REXT)
unnamed: R18.1, R19.1, U5.18 (VBUSM)
unnamed: C25.1, Q2.1, U5.3 (XI)
unnamed: C26.1, Q2.2, U5.2 (XO)
VBUS: D1.2 (A), T1.1 (B), USB-PGM1.A4 (VBUS), USB-PGM1.A9 (VBUS), USB-PGM1.B4 (VBUS), USB-PGM1.B9 (VBUS)

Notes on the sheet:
USB-PWR Input
The VBUS Monitor (Input, 5V-Tolerant) of upstream facing port.
The CH217K's FLAG# pin can generate an over-current or over-temperature alarm signal to notify the HUB controller and the computer, and the CH334/5 has built-in pull-up resistors.
(The Board's Power Supply Connector)
QSPI pins of RP2040 should be wired directly to the flash, using short connections
USB-HUB
Integrated 12MHz Oscillator with feedback resistor, and crystal load capacitance; Load capacitance: 16pF ~ 20pF
(Video Output)
6502 MCU
Rset
Upstream facing port supports HighSpeed (480MHz) and Full-Speed (12MHz) modes; 4 downstream facing ports support High-Speed (480MHz), Full-Speed (12MHz), and Low-Speed (1.5MHz) modes;
(Firmware Upgrade)
XRSTJ - External Reset For normal applications, it should be pull-up to 3.3V.
Close to RPi!
Coil Resistance = 16R Current(max) = 50mA
USB-PGM
UEXT
FE1.1s POWER CONSUMPTION: I_suspend = 800uA Icc(4x High-Speed) = 84mA
Mounting Holes
REXT - External Bias Resistor. A 2.7KΩ (± 1%) resistor should be connected to VSS to provide internal bias reference.
FE1.1s is USB 2.0 HIGH SPEED 4-PORT HUB CONTROLLER
Ilim(A)=60K/Rset
Fiducials
Audio
Bus power indicator: 0 - Bus Powered; 1 - Self Powered; (Input, 5V-Tolerant)
Ilim=1.82A
RP2040 PGM/DBG
DVI
Over Current Indicator (Input, 5V-Tolerant), active low, for Global Over-Current Protection. VIL=-0.3~0.8V, VIH=2.0~5.5V
RP2040
PWRJ - Power Enable Output (OD) This is an active low, open-drain output signal. Downstream Device Power Enable (Output), active low, for Ganged Power Switching.
Power Supply
Vout=0.6*(1+Ra/Rb)
Test Mode Enable (I/O), active low with internal pull-up, and external Serial EEPROM Data/Address.
Flash Memory 16Mbit(2MB)

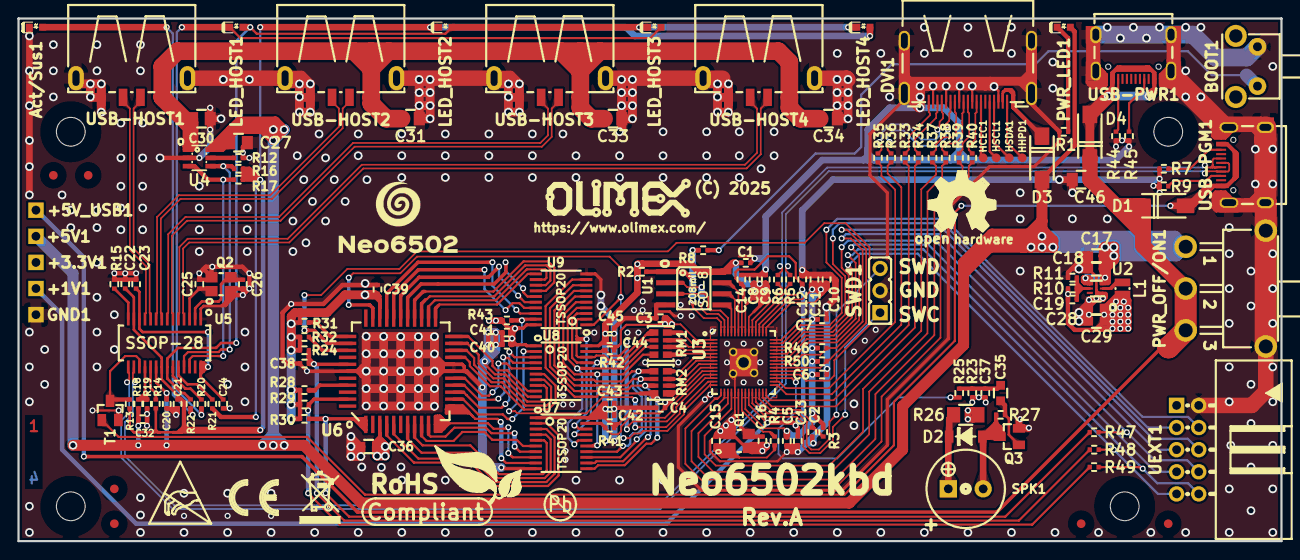
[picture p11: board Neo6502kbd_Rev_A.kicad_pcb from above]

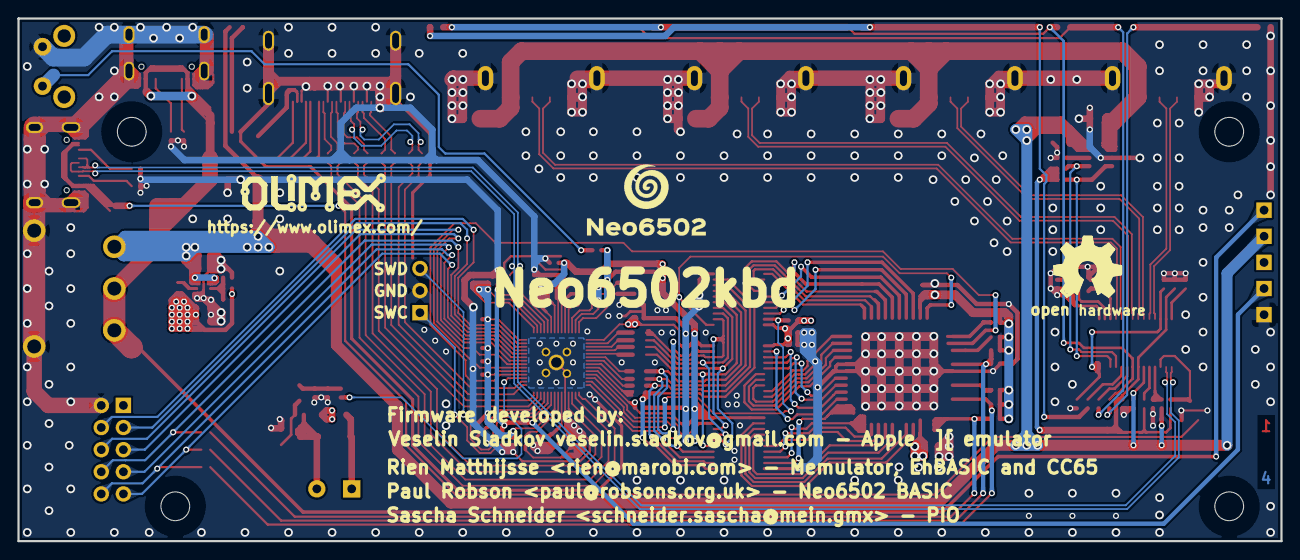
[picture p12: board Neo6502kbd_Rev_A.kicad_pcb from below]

Board: 4 copper layers, 145.0 x 60.0 mm, 165 parts (7 on the bottom side), 141 nets.

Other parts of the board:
Logo_OLIMEX_TB-Bottom: Logo_OLIMEX_TB
Logo_OLIMEX_TB-Top: Logo_OLIMEX_TB
NEO_LOGO_SMALL*: LOGO; Neo6502_Sign_Small
NEO_LOGO_SMALL-Top: LOGO; Neo6502_Sign_Small
Sign_Antistatic: Sign_Antistatic
Sign_CE: CE_Sign
Sign_OSHW_8x8, Sign_OSHW_8x8-Top: Sign_OSHW_8x8
Sign_PB-Free: Sign_PB-Free
Sign_RecycleBin: Sign_RecycleBin; Sign_RecycleBin_1
Sign_RoHS: Sign_RoHS; Sign_RoHS_1

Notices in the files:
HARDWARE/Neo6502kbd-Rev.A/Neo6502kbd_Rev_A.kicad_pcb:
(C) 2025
